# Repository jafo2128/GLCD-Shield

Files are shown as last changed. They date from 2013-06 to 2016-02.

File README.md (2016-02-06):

# GLCD-Shield
The GLCD-Shield is a plug-on module with color display (128x128 pixel) and rotary encoder/navigation switch for Arduino/Genuino.

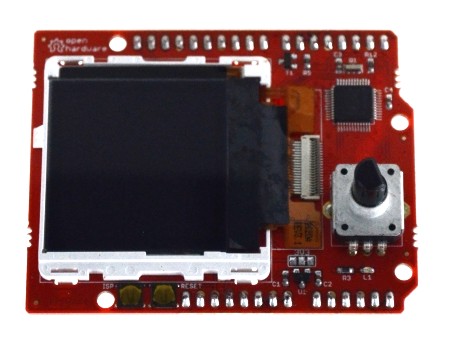
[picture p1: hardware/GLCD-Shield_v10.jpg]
GLCD-Shield (http://www.watterott.com/en/Arduino-GLCD-Shield-Joystick)


## Shop
* [GLCD-Shield with Rotary-Encoder](http://www.watterott.com/en/Arduino-GLCD-Shield)
* [GLCD-Shield with Joystick](http://www.watterott.com/en/Arduino-GLCD-Shield-Joystick)

## Features
* Color display with 128x128 pixel
* Rotary-Encoder or Joystick / Navigation-Switch
* Controller: NXP LPC1114 ARM Cortex-M0 with Open-Source Firmware
* Interface: UART, I2C, SPI/SSI (Mode 3, up to 4MHz)
* Backlight dimmable via interface
* 3.3V - 5V tolerant IOs

## Hardware
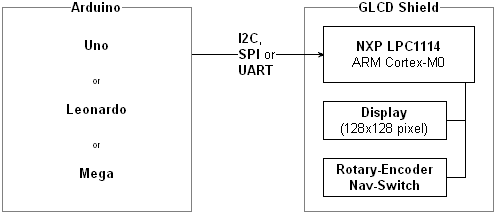
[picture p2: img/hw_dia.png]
GLCD-Shield hardware dia
* 
* [Schematics + Layout](https://github.com/watterott/GLCD-Shield/tree/master/hardware)

## Software
* [General Arduino Examples](https://github.com/watterott/MI0283QT-Adapter/tree/master/firmware/examples)
* [Arduino Library and Examples](https://github.com/watterott/Arduino-Libs)
* [Firmware Source Code](https://github.com/watterott/MI0283QT-Adapter/tree/master/firmware)
* [Firmware Update Guide](https://github.com/watterott/MI0283QT-Adapter/blob/master/firmware/update_guide/README.md)
* [Command Description](https://github.com/watterott/MI0283QT-Adapter/blob/master/firmware/docu/README.md)

Finally words from us Archivers and Developers.. 

##### Donate

People from time to time wish to donate a little money. Donating won't get you anything special, other than a warm feeling inside, and possibly urge me to produce more freely available material for interesting projects. You can donate via [PayPal](https://www.paypal.com), just click [donate](https://www.paypal.com/cgi-bin/webscr?cmd=_s-xclick&hosted_button_id=3PXVSLXFBS45E) button available below - it will redirect you to the secured PayPal page where you can provide donation amount (there is no minimal value). Any donations are apreciated greatly, and we thank you all in advance for your support along the ways..



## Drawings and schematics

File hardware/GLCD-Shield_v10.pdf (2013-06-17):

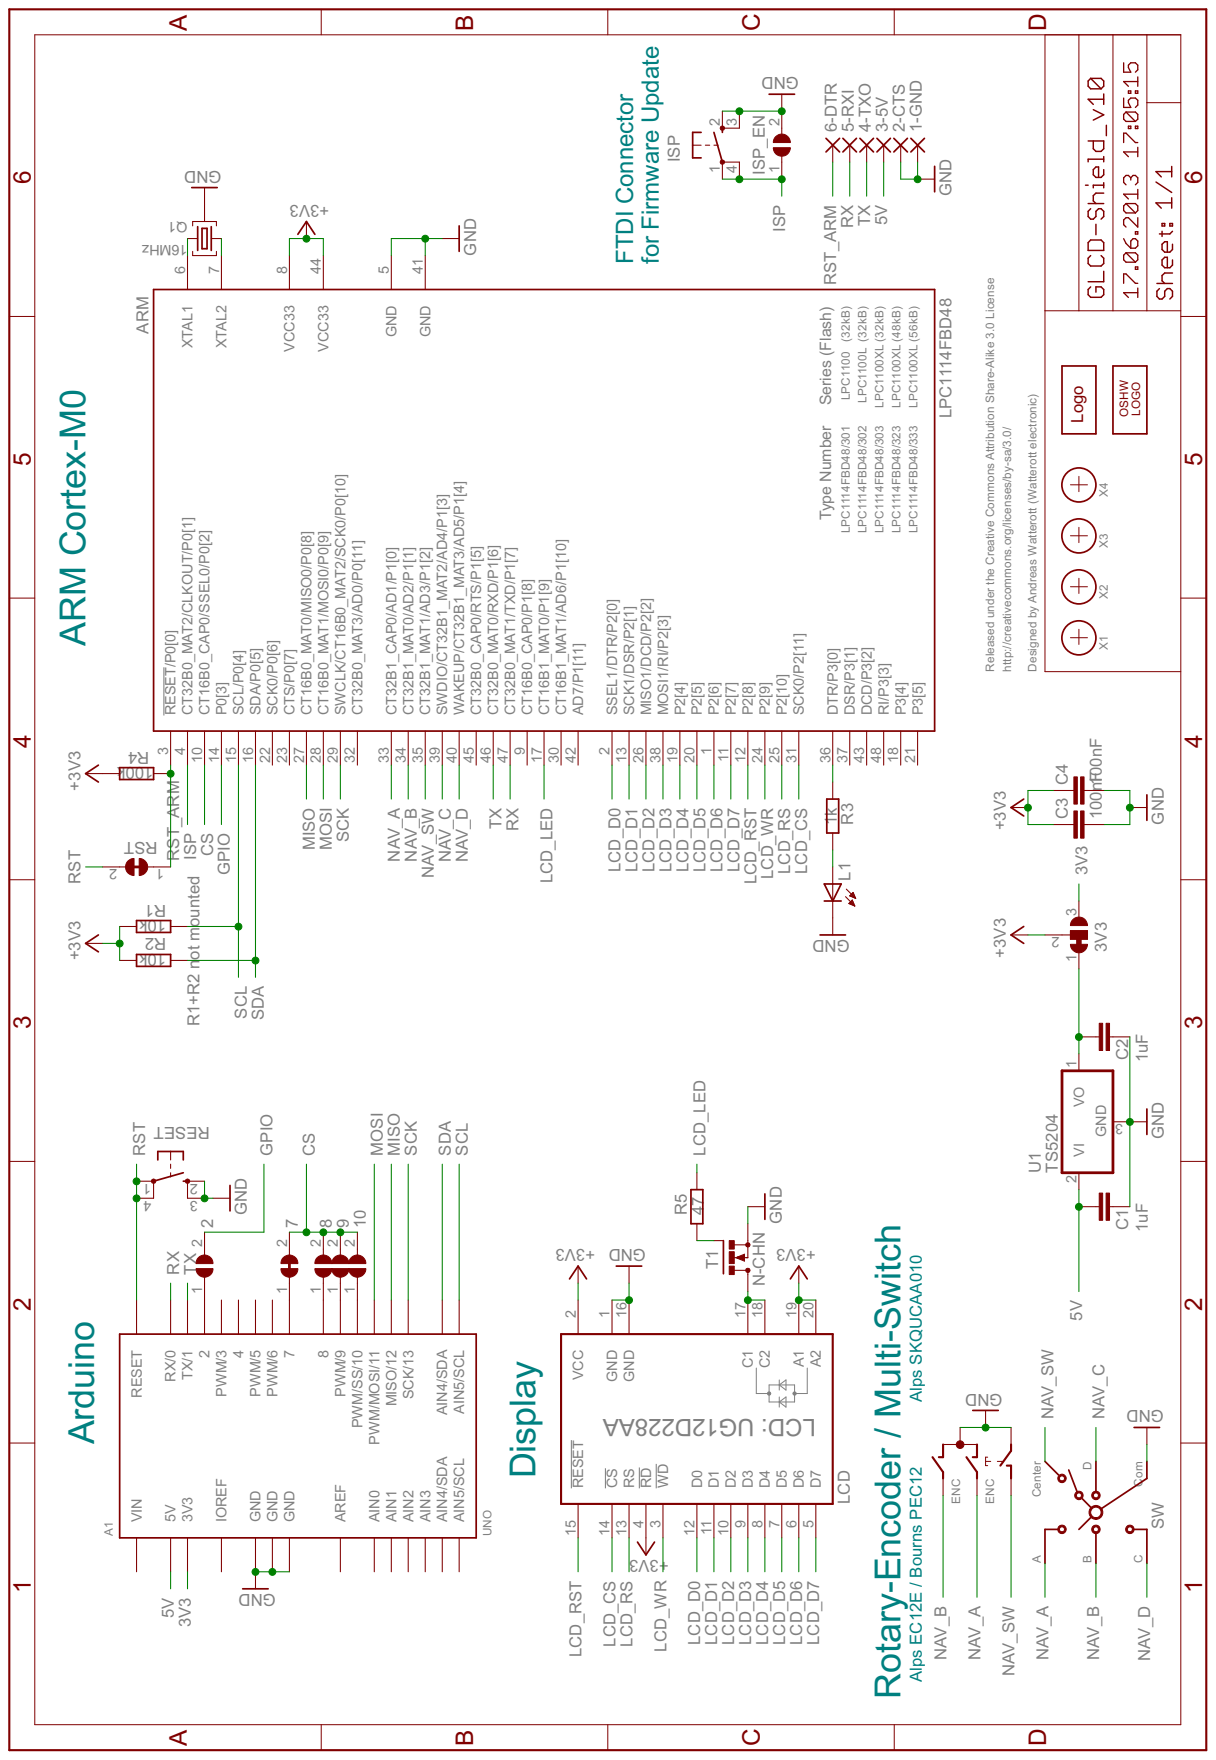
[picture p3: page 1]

Released under the Creative Commons Attribution Share-Alike 3.0 License

Type Number Series (Flash) LPC1114FBD48/301

http://creativecommons.org/licenses/by-sa/3.0/ Designed by Andreas Watterott (Watterott electronic)

CT16B1_MAT0/P1[9] 17 CT16B0_CAP0/P1[8] 9 CT32B0_MAT1/TXD/P1[7] 47 CT32B0_MAT0/RXD/P1[6] 46 CT32B0_CAP0/RTS/P1[5] 45 WAKEUP/CT32B1_MAT3/AD5/P1[4] 40 SWDIO/CT32B1_MAT2/AD4/P1[3] 39 CT32B1_MAT1/AD3/P1[2] 35 CT32B1_MAT0/AD2/P1[1] 34 CT32B1_CAP0/AD1/P1[0] 33

P2[9] 24 P2[8] 12 P2[7] 11 P2[6] 1 P2[5] 20 P2[4] 19 MOSI1/RI/P2[3] 38 MISO1/DCD/P2[2] 26 SCK1/DSR/P2[1] 13 SSEL1/DTR/P2[0] 2

Alps EC12E / Bourns PEC12 Alps SKQUC

8 PWM/9 PWM/SS/10 PWM/MOSI/11 MISO/12 SCK/13 AIN1 AIN2 AIN3 AIN4/SDA

IOREF GND GND GND

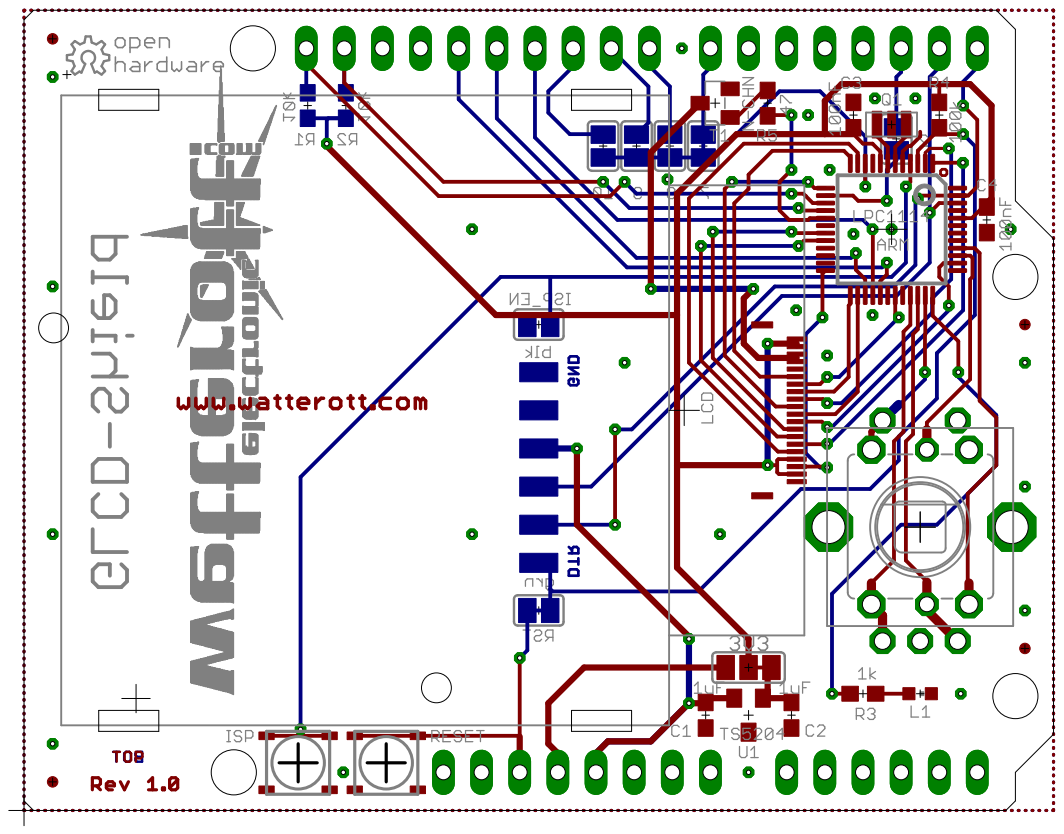
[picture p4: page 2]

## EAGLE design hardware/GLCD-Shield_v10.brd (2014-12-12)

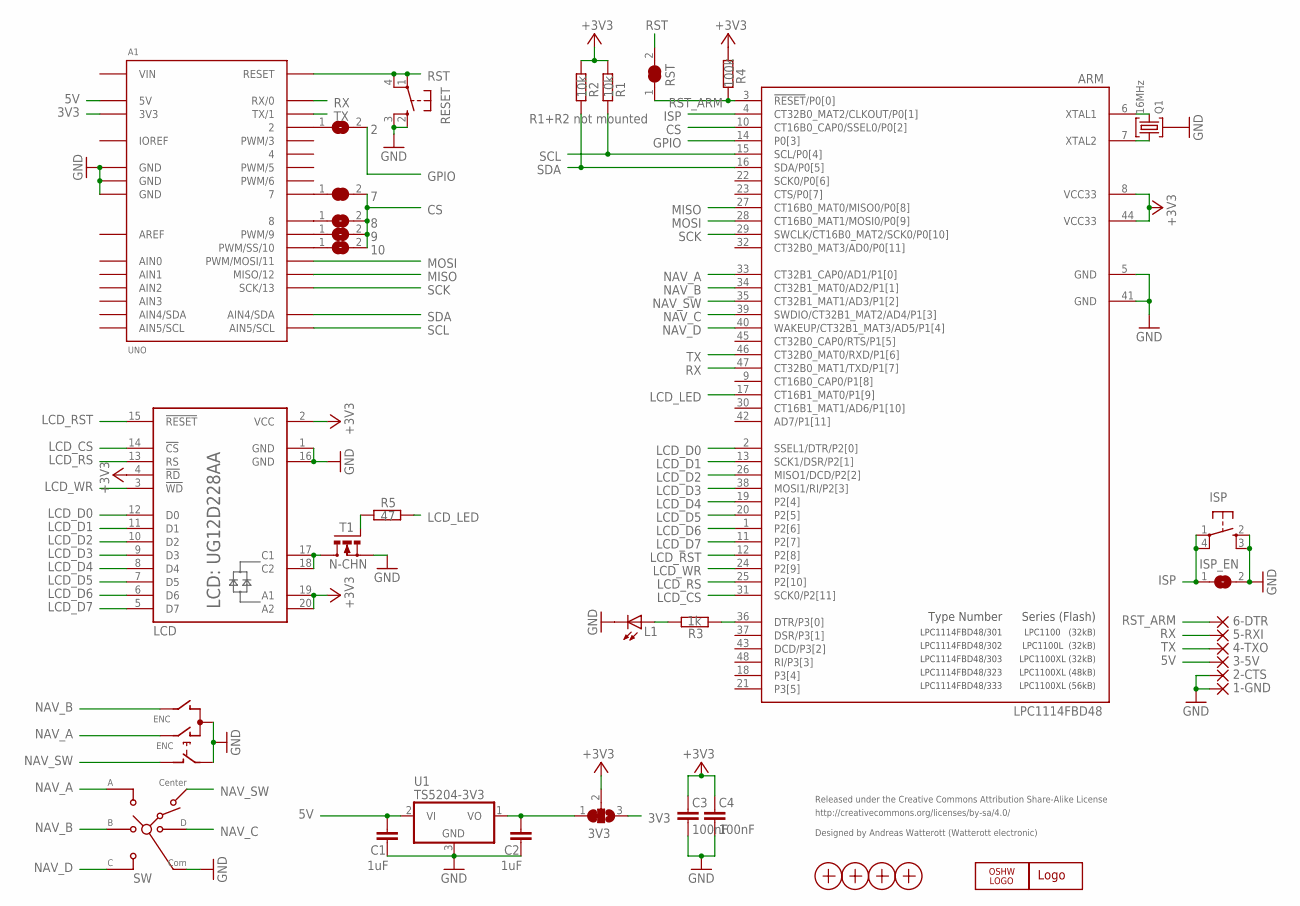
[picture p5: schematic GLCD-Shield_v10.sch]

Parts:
1-GND, 2-CTS, 3-5V, 4-TXO, 5-RXI, 6-DTR: WIREPADSMD1,27-254; SMD1,27-2,54
2, 7, 8, 9, 10: SJ
3V3: SJ2W; SJ_2
A1: UNO
ARM: LPC1114FBD48; LQFP48
C1, C2: 1uF; C0603
C3, C4: 100nF; C0603
ENC: EC12E_SW; ALPS_EC12E_SW
ISP: SW_SMDS; SW_SMD4@1
ISP_EN: SJ
L1: LEDCHIPLED_0603; CHIPLED_0603
LCD: UG12D228AA
LOGO1: OSHW_LOGO_6MILX0100-NT; OSHW_6X100_NOTEXT
Q1: 16MHz; SMD_OSC_35X15
R1, R2: 10k; R0603
R3: 1k; R0603
R4: 100k; R0603
R5: 47; R0603
RESET: SW_SMDS; SW_SMD4@1
RST: SJ
SW: SKQUCAA010; SKQU
T1: N-CHN; MICRO3
U1: TS5204-3V3; SOT23
U$1: WE-LOGOPLACE; WE-LOGO
X1, X2, X3, X4: PASSER

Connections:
2X: 2.1, A1.2
3V3: 3V3.3, A1.3V3
3V_OUT: 3V3.1, C2.1, U1.1 (VO)
5V: 3-5V.1, A1.5V, C1.1, U1.2 (VI)
7: 7.1, A1.7
8: 8.1, A1.8
9: 9.1, A1.9 (PWM/9)
10: 10.1, A1.10 (PWM/SS/10)
+3V3: 3V3.2, ARM.8 (VCC33), ARM.44 (VCC33), C3.1, C4.1, LCD.2 (VCC), LCD.4 (!RD), LCD.19 (A1), LCD.20 (A2), R1.2, R2.2, R4.2
AREF: A1.AREF
C: LCD.17 (C1), LCD.18 (C2), T1.3 (D)
CS: 7.2, 8.2, 9.2, 10.2, ARM.10 (CT16B0_CAP0/SSEL0/P0[2])
GND: 1-GND.1, 2-CTS.1, A1.GND@1 (GND), A1.GND@2 (GND), A1.GND@3 (GND), ARM.5 (GND), ARM.41 (GND), C1.2, C2.2, C3.2, C4.2, ENC.C, ENC.E (2), ISP.2 (S), ISP.3 (S1), ISP_EN.2, L1.C, LCD.1 (GND), LCD.16 (GND), Q1.GND, RESET.2 (S), RESET.3 (S1), SW.COMMON, T1.2 (S), U1.3 (GND)
GPIO: 2.2, ARM.14 (P0[3])
IOREF: A1.IOREF
ISP: ARM.4 (CT32B0_MAT2/CLKOUT/P0[1]), ISP.1, ISP.4 (P1), ISP_EN.1
LCD_CS: ARM.31 (SCK0/P2[11]), LCD.14 (!CS)
LCD_D0: ARM.2 (SSEL1/DTR/P2[0]), LCD.12 (D0)
LCD_D1: ARM.13 (SCK1/DSR/P2[1]), LCD.11 (D1)
LCD_D2: ARM.26 (MISO1/DCD/P2[2]), LCD.10 (D2)
LCD_D3: ARM.38 (MOSI1/RI/P2[3]), LCD.9 (D3)
LCD_D4: ARM.19 (P2[4]), LCD.8 (D4)
LCD_D5: ARM.20 (P2[5]), LCD.7 (D5)
LCD_D6: ARM.1 (P2[6]), LCD.6 (D6)
LCD_D7: ARM.11 (P2[7]), LCD.5 (D7)
LCD_LED: ARM.17 (CT16B1_MAT0/P1[9]), R5.2
LCD_RS: ARM.25 (P2[10]), LCD.13 (RS)
LCD_RST: ARM.12 (P2[8]), LCD.15 (!RESET)
LCD_WR: ARM.24 (P2[9]), LCD.3 (!WD)
LED: ARM.36 (DTR/P3[0]), R3.1
LEDPWM: R5.1, T1.1 (G)
MISO: A1.12 (MISO/12), ARM.27 (CT16B0_MAT0/MISO0/P0[8])
MOSI: A1.11 (PWM/MOSI/11), ARM.28 (CT16B0_MAT1/MOSI0/P0[9])
unnamed: ARM.6 (XTAL1), Q1.2
unnamed: ARM.7 (XTAL2), Q1.1
unnamed: L1.A, R3.2
NAV_A: ARM.33 (CT32B1_CAP0/AD1/P1[0]), ENC.A, SW.A
NAV_B: ARM.34 (CT32B1_MAT0/AD2/P1[1]), ENC.B, SW.B
NAV_C: ARM.39 (SWDIO/CT32B1_MAT2/AD4/P1[3]), SW.D
NAV_D: ARM.40 (WAKEUP/CT32B1_MAT3/AD5/P1[4]), SW.C
NAV_SW: ARM.35 (CT32B1_MAT1/AD3/P1[2]), ENC.D (1), SW.CENTER
RST: A1.RST (RESET), RESET.1, RESET.4 (P1), RST.2
RST_ARM: 6-DTR.1, ARM.3 (!RESET!/P0[0]), R4.1, RST.1
RX: 5-RXI.1, A1.0 (RX/0), ARM.47 (CT32B0_MAT1/TXD/P1[7])
SCK: A1.13 (SCK/13), ARM.29 (SWCLK/CT16B0_MAT2/SCK0/P0[10])
SCL: A1.SCL (AIN5/SCL), ARM.15 (SCL/P0[4]), R1.1
SDA: A1.SDA (AIN4/SDA), ARM.16 (SDA/P0[5]), R2.1
TX: 4-TXO.1, A1.1 (TX/1), ARM.46 (CT32B0_MAT0/RXD/P1[6])
VIN: A1.VIN

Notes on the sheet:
Released under the Creative Commons Attribution Share-Alike License
http://creativecommons.org/licenses/by-sa/4.0/
Designed by Andreas Watterott (Watterott electronic)
R1+R2 not mounted
LPC1100 (32kB)
LPC1100L (32kB)
LPC1100XL (32kB)
LPC1100XL (48kB)
LPC1100XL (56kB)
Type Number
Series (Flash)
LPC1114FBD48/301
LPC1114FBD48/302
LPC1114FBD48/303
LPC1114FBD48/323
LPC1114FBD48/333

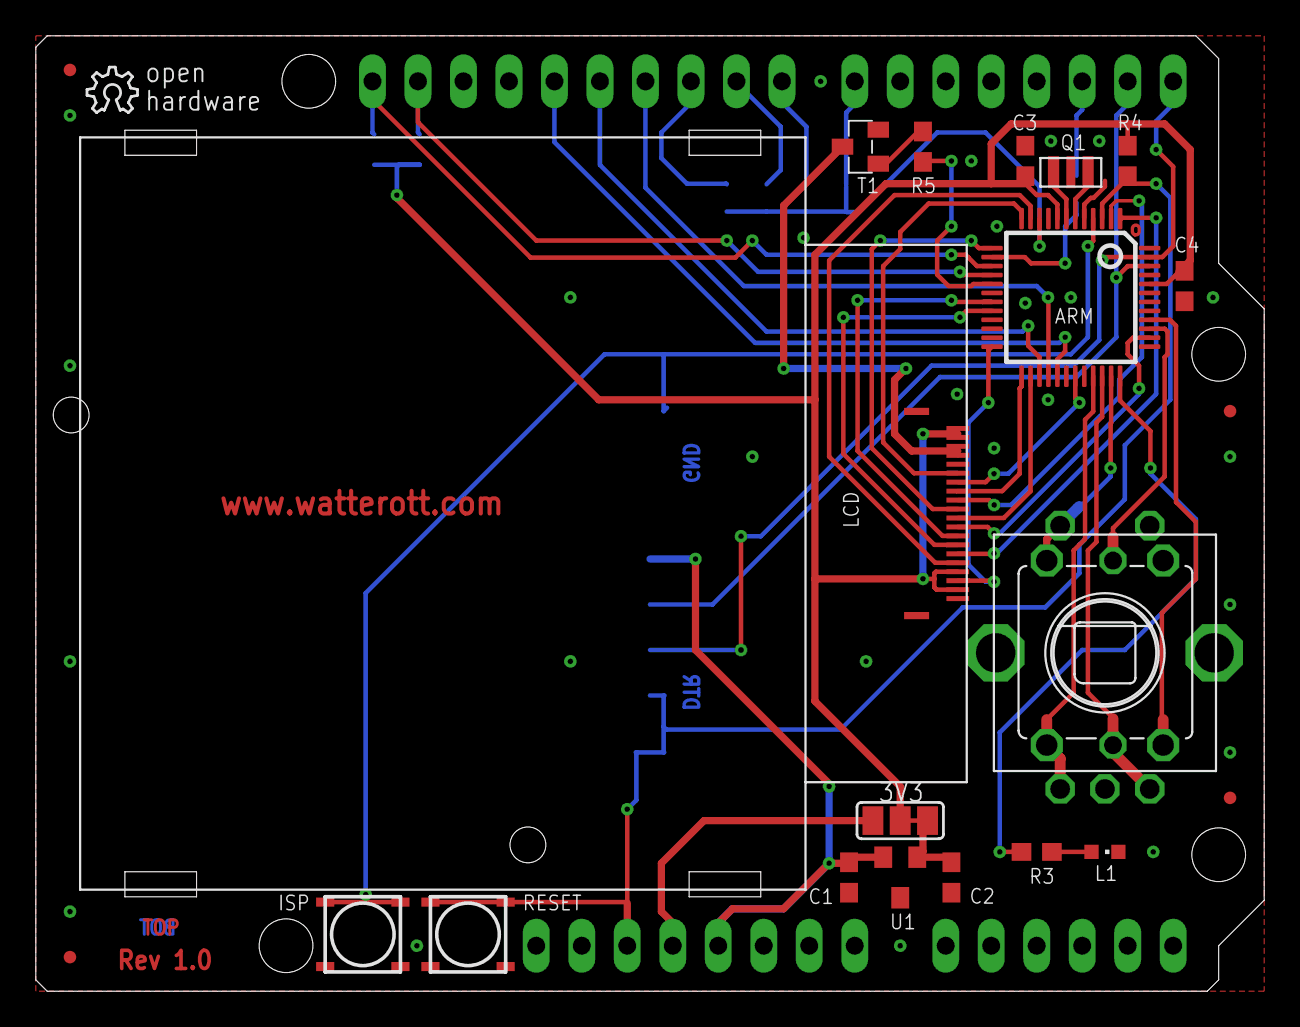
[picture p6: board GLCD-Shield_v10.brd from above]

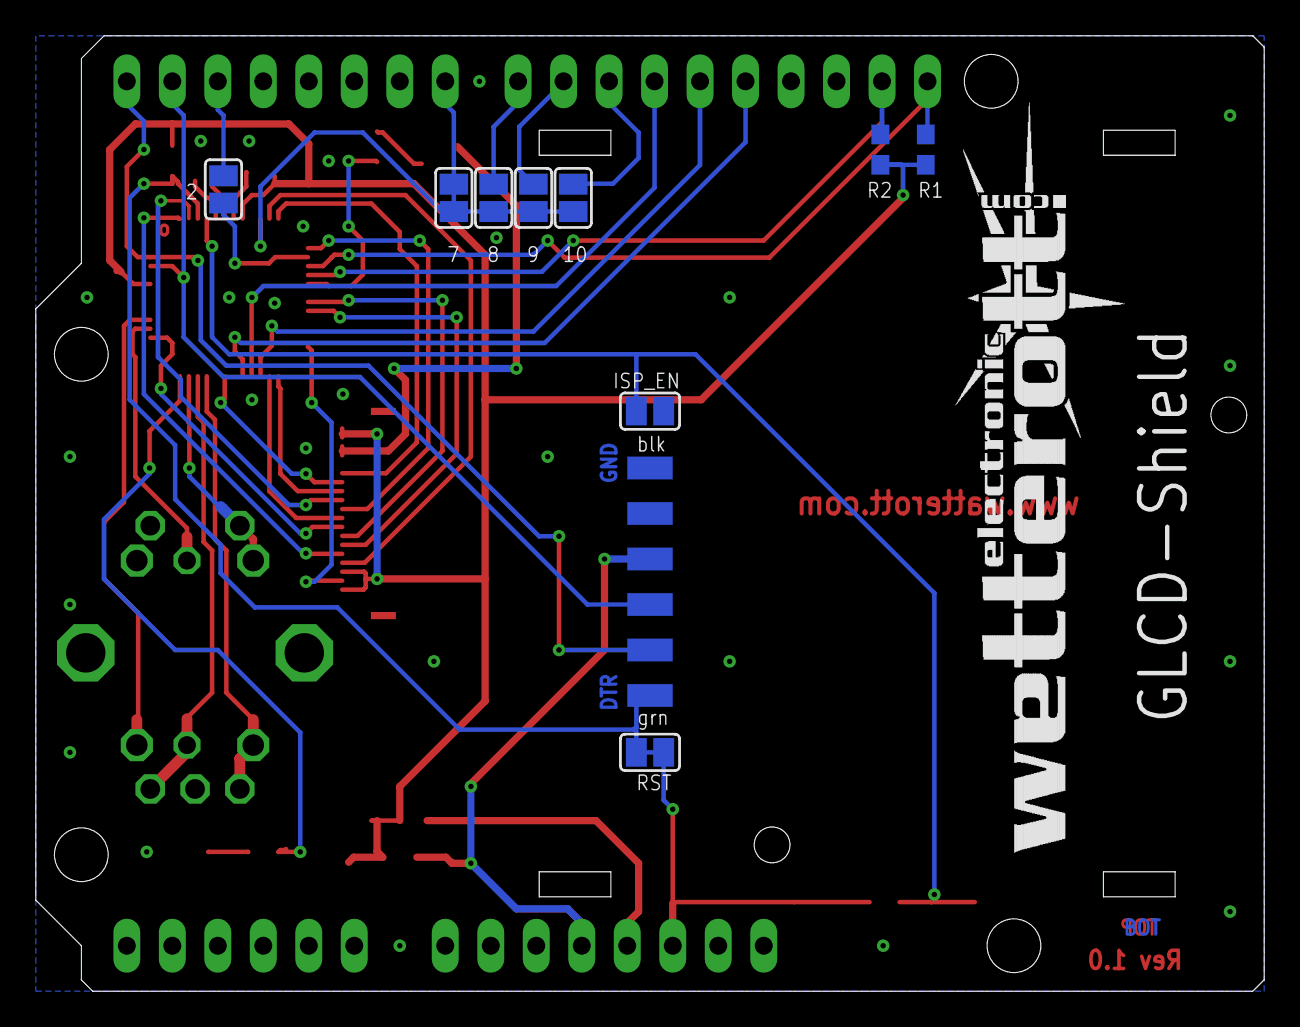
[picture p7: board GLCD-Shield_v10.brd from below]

Board: 2 copper layers, 68.6 x 53.3 mm, 40 parts (16 on the bottom side), 46 nets.

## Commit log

2013-05-27 added schematic and image
2013-06-17 updated schematics
    [GLCD-Shield_v10.brd, GLCD-Shield_v10.sch]
2014-03-10 updated license infos
    [GLCD-Shield_v10.sch]
2014-08-15 updated schematic and layout files
    [GLCD-Shield_v10.brd, GLCD-Shield_v10.sch]
2014-08-21 updated layout and schematics
    [GLCD-Shield_v10.brd]
2014-11-06 cleaned up schematics and layout
    [GLCD-Shield_v10.brd, GLCD-Shield_v10.sch]
2015-08-21 changed path structure
    [GLCD-Shield_v10.brd, GLCD-Shield_v10.sch]
